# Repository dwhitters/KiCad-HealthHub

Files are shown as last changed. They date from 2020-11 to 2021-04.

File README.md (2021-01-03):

# KiCad-HealthHub
Schematic and PCB layout for the health hub.

## Overview
This PCB provides basic signal processing for an ECG input. The processed signal is then fed into a bluetooth module that can be used to provide data to a corresponding phone app, such as https://github.com/DaveAldon/Health-Hub-Mobile. Additional microcontroller pins are broken out to facilitate development of additional features.

## Images
Front

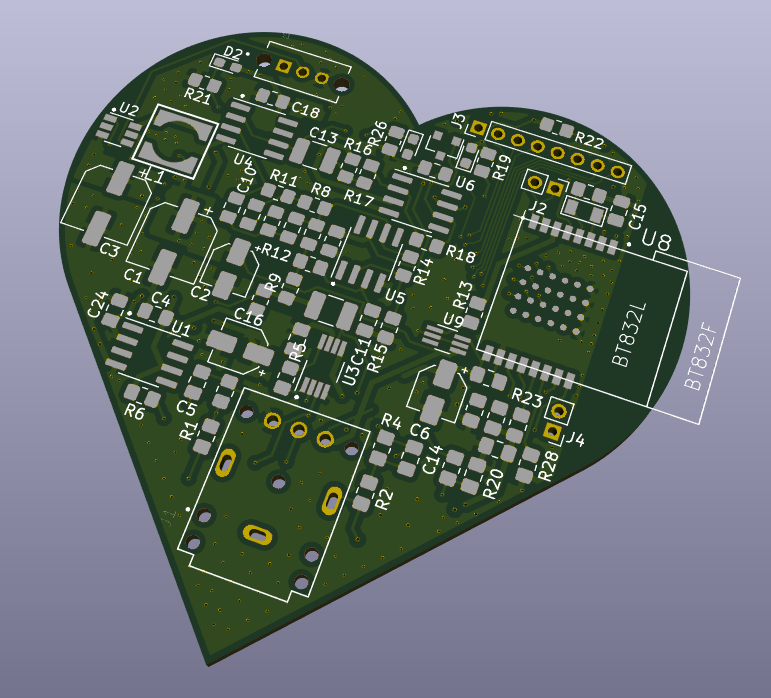
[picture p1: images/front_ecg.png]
Front


Back

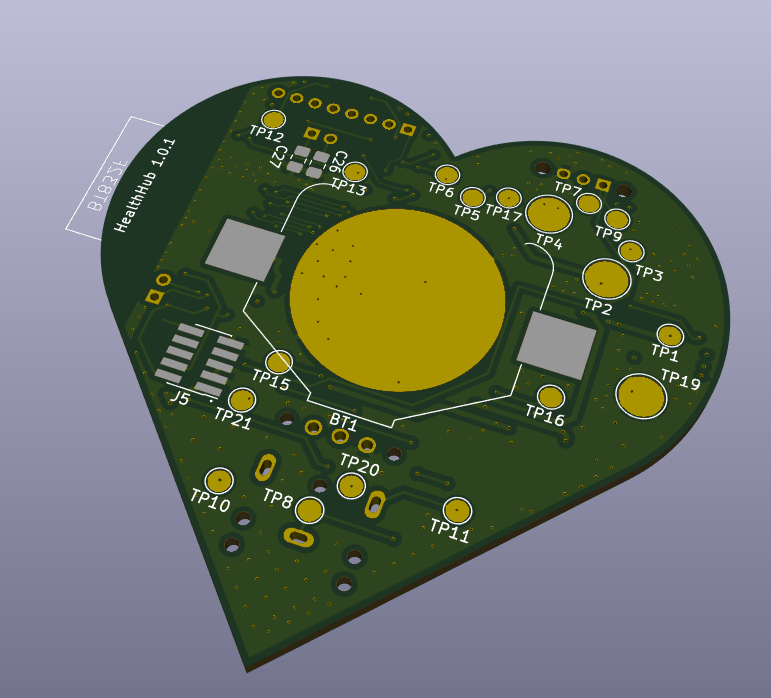
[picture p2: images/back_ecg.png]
Back


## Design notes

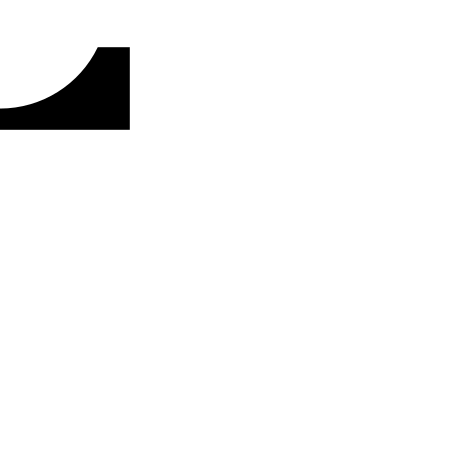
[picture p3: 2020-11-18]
Custom_Footprint/.svg2shenzhen-cache/images/F.SilkS_g23.png

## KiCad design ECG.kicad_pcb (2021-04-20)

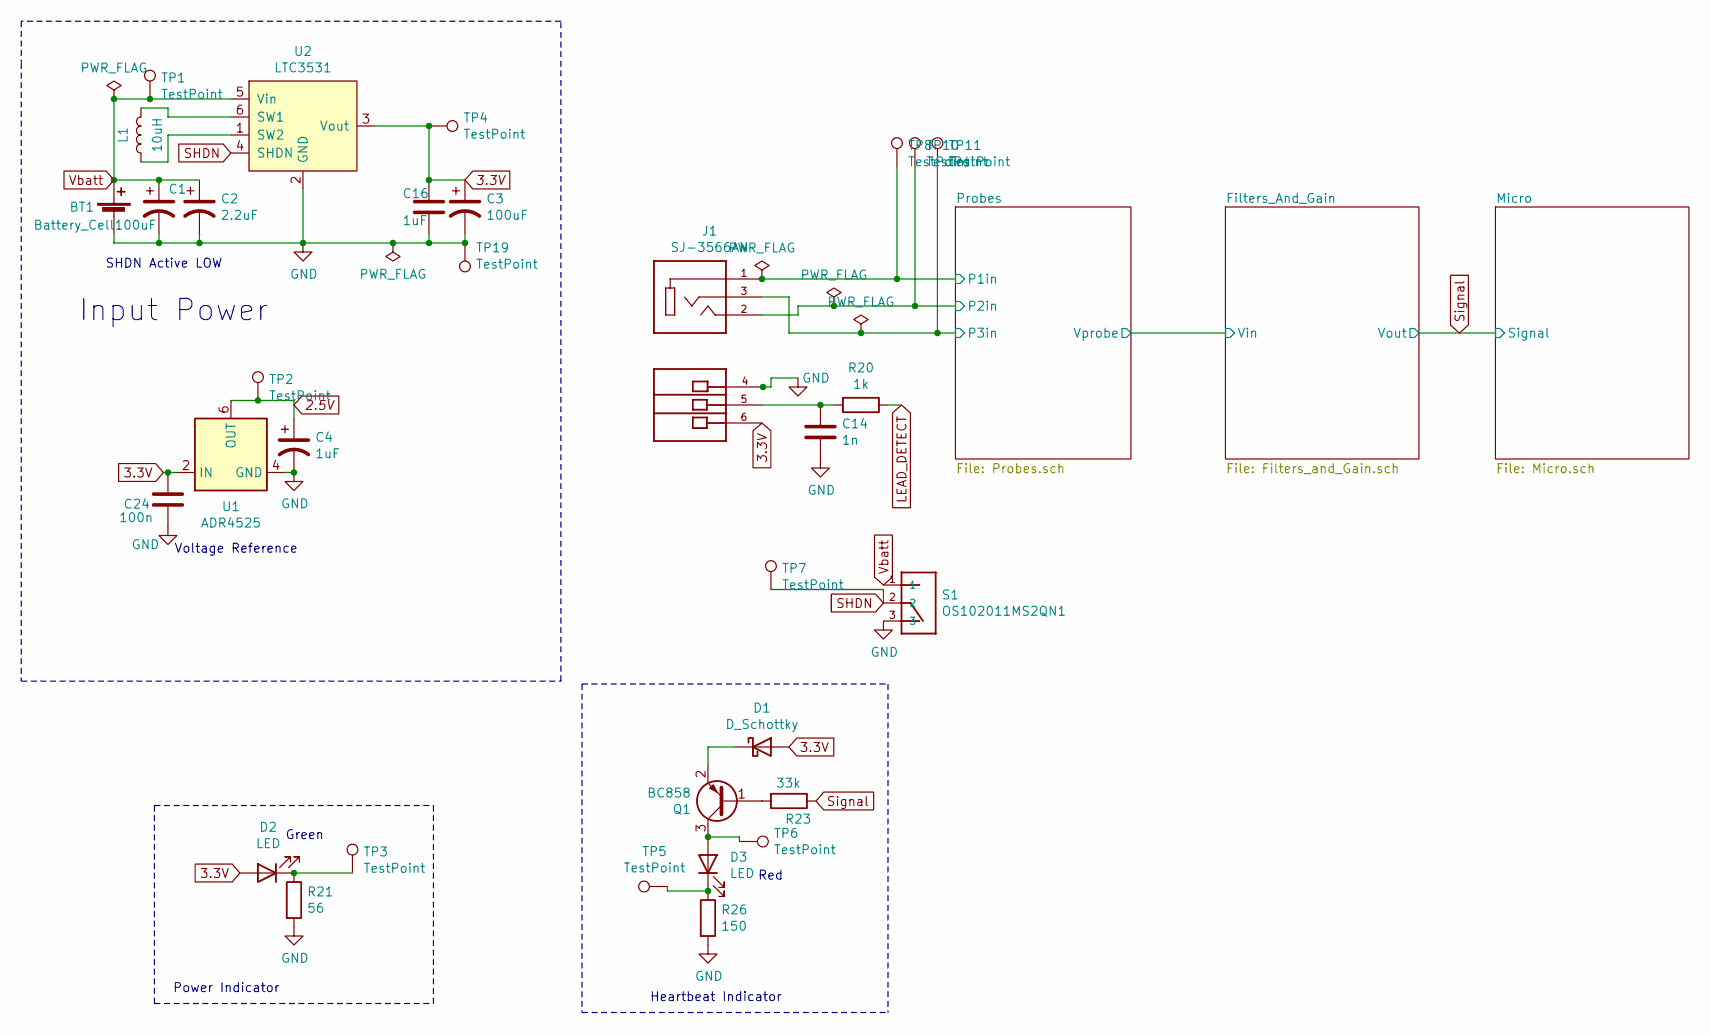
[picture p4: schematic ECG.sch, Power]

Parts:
BT1: Battery_Cell; BatteryHolder_Keystone_3008_1x2450
C1, C3: 100uF; CP_Elec_6.3x5.3
C2: 2.2uF; CP_Elec_4x5.7
C4: 1uF; C_0805_2012Metric_Pad1.18x1.45mm_HandSolder
C14: 1n; C_0805_2012Metric_Pad1.18x1.45mm_HandSolder
C16: 1uF; CP_Elec_4x5.3
C24: 100n; C_0805_2012Metric_Pad1.18x1.45mm_HandSolder
D1: D_Schottky; D_0603_1608Metric_Pad1.05x0.95mm_HandSolder
D2, D3: LED; D_0603_1608Metric_Pad1.05x0.95mm_HandSolder
J1: SJ-3566AN; CUI_SJ-3566AN
L1: 10uH; L_Sumida_CDRH5D28
Q1: BC858; SOT-23
R20: 1k; R_0805_2012Metric_Pad1.20x1.40mm_HandSolder
R21: 56; R_0805_2012Metric_Pad1.20x1.40mm_HandSolder
R23: 33k; R_0805_2012Metric_Pad1.20x1.40mm_HandSolder
R26: 150; R_0805_2012Metric_Pad1.20x1.40mm_HandSolder
S1: OS102011MS2QN1; SW_OS102011MS2QN1
TP1, TP3, TP5, TP6, TP7, TP8, TP10, TP11: TestPoint; TestPoint_Pad_D2.0mm
TP2, TP4, TP19: TestPoint; TestPoint_Pad_D4.0mm
U1: ADR4525; SOIC-8_3.9x4.9mm_P1.27mm
U2: LTC3531; TSOT-23-6

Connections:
2.5V: C4.1, TP2.1, U1.6 (OUT); also elsewhere on the board
3.3V: C3.1, C16.1, C24.1, D1.2 (A), D2.2 (A), J1.6, TP4.1, U1.2 (IN), U2.3 (Vout); also elsewhere on the board
/Probes/P1in: J1.1, TP8.1; also elsewhere on the board
/Probes/P2in: J1.2, TP10.1; also elsewhere on the board
/Probes/P3in: J1.3, TP11.1; also elsewhere on the board
GND: BT1.2 (-), C1.2, C2.2, C3.2, C4.2, C14.2, C16.2, C24.2, J1.4, R21.2, R26.2, S1.3, TP19.1, U1.4 (GND), U2.2 (GND); also elsewhere on the board
LEAD_DETECT: R20.1; also elsewhere on the board
unnamed: C14.1, J1.5, R20.2
unnamed: D1.1 (K), Q1.2 (E)
unnamed: D2.1 (K), R21.1, TP3.1
unnamed: D3.1 (K), R26.1, TP5.1
unnamed: D3.2 (A), Q1.3 (C), TP6.1
unnamed: L1.1, U2.1 (SW2)
unnamed: L1.2, U2.6 (SW1)
unnamed: Q1.1 (B), R23.2
SHDN: S1.2, TP7.1, U2.4 (SHDN); also elsewhere on the board
Signal: R23.1; also elsewhere on the board
Vbatt: BT1.1 (+), C1.1, C2.1, S1.1, TP1.1, U2.5 (Vin); also elsewhere on the board

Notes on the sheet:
Input Power
Voltage Reference
SHDN Active LOW
Power Indicator
Green
Red
Heartbeat Indicator

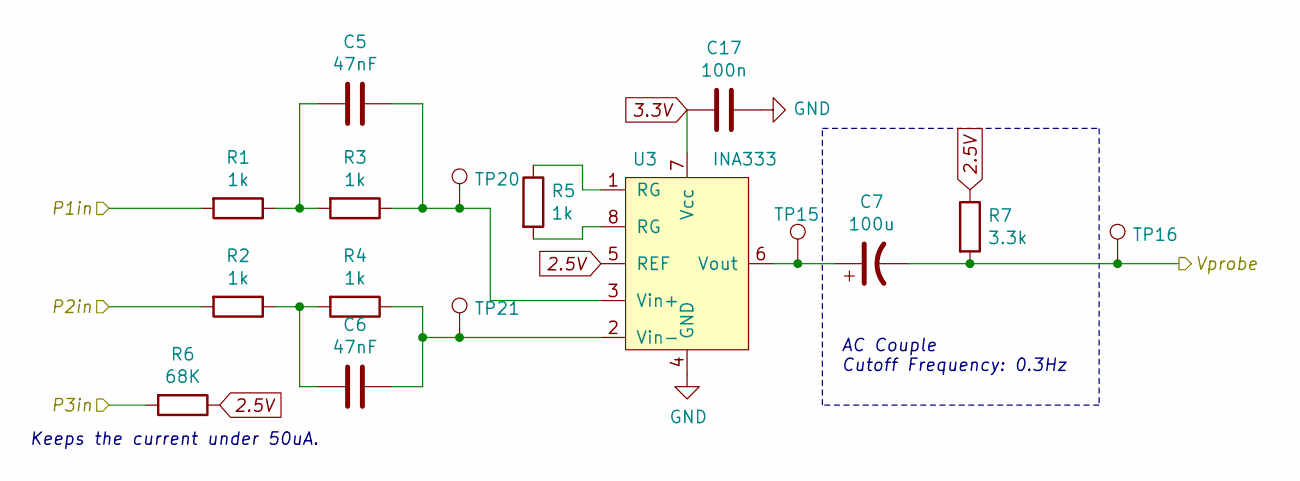
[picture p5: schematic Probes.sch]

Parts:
C5, C6: 47nF; C_0805_2012Metric_Pad1.18x1.45mm_HandSolder
C7: 100u; C_1210_3225Metric_Pad1.33x2.70mm_HandSolder
C17: 100n; C_0805_2012Metric_Pad1.18x1.45mm_HandSolder
R1, R2, R3, R4, R5: 1k; R_0805_2012Metric_Pad1.20x1.40mm_HandSolder
R6: 68K; R_0805_2012Metric_Pad1.20x1.40mm_HandSolder
R7: 3.3k; R_0805_2012Metric_Pad1.20x1.40mm_HandSolder
TP15, TP16, TP20, TP21: TestPoint; TestPoint_Pad_D2.0mm
U3: INA333; VSSOP-8_3.0x3.0mm_P0.65mm

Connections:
2.5V: R6.1, R7.1, U3.5 (REF); also elsewhere on the board
3.3V: C17.2, U3.7 (Vcc); also elsewhere on the board
/Filters_And_Gain/Vin: C7.2, R7.2, TP16.1; also elsewhere on the board
/Probes/P1in: R1.2; also elsewhere on the board
/Probes/P2in: R2.2; also elsewhere on the board
/Probes/P3in: R6.2; also elsewhere on the board
GND: C17.1, U3.4 (GND); also elsewhere on the board
unnamed: C5.1, R3.1, TP20.1, U3.3 (Vin+)
unnamed: C5.2, R1.1, R3.2
unnamed: C6.1, R4.1, TP21.1, U3.2 (Vin-)
unnamed: C6.2, R2.1, R4.2
unnamed: C7.1, TP15.1, U3.6 (Vout)
unnamed: R5.1, U3.1 (RG)
unnamed: R5.2, U3.8 (RG)

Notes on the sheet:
Keeps the current under 50uA.
AC Couple Cutoff Frequency: 0.3Hz

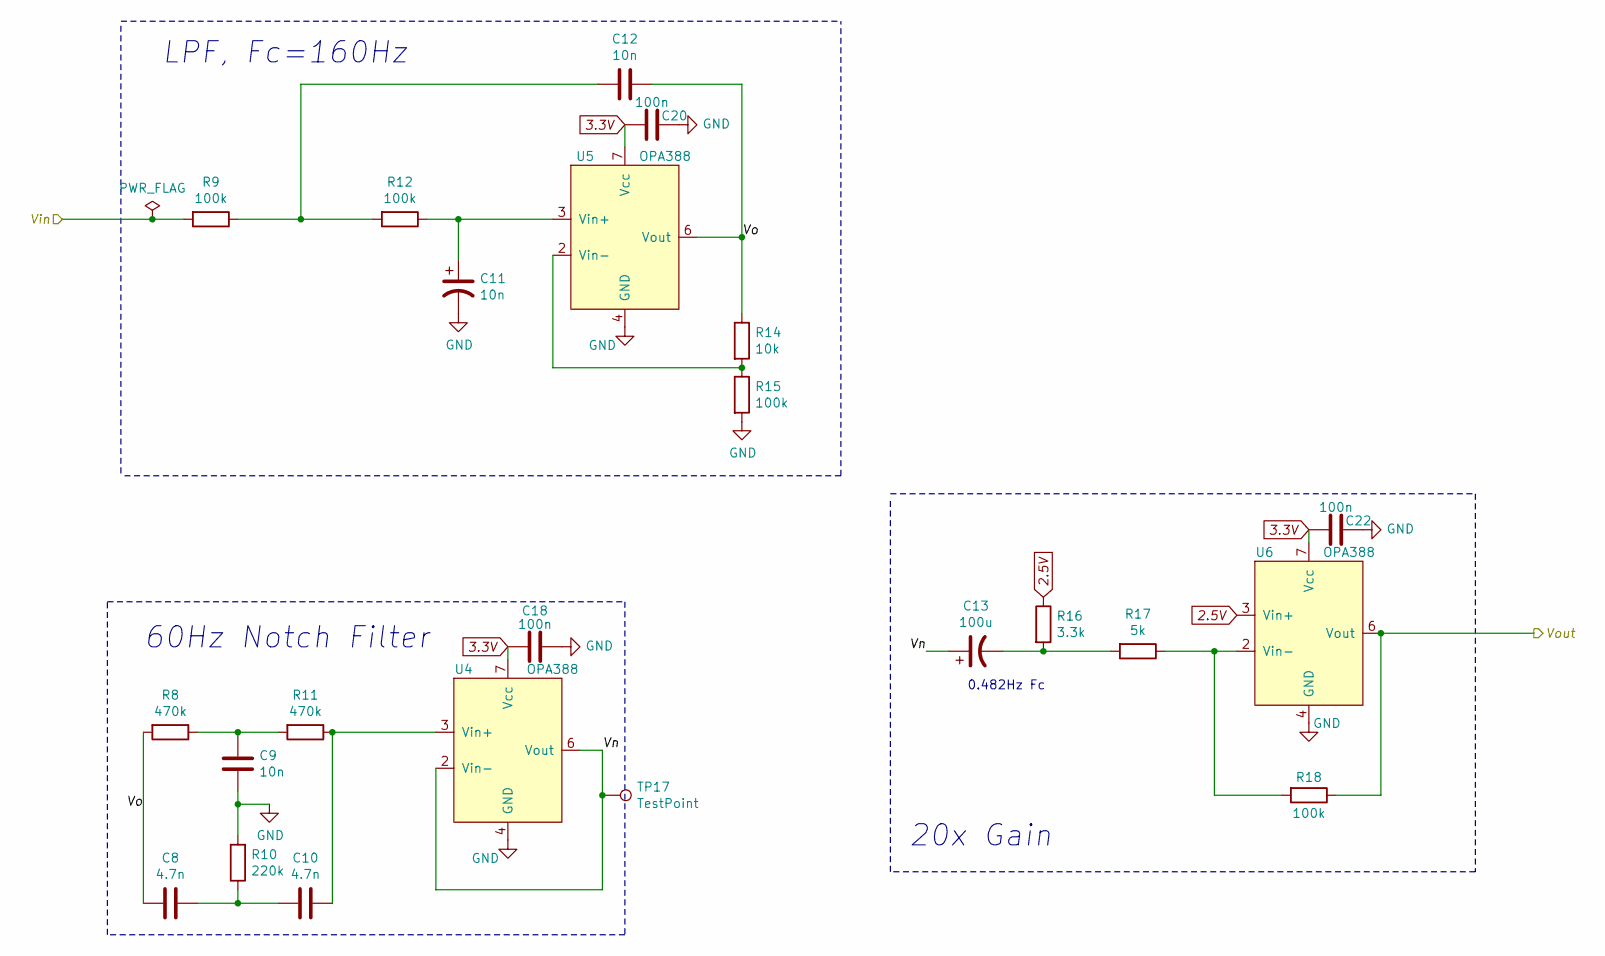
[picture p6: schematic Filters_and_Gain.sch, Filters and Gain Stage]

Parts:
C8, C10: 4.7n; C_0805_2012Metric_Pad1.18x1.45mm_HandSolder
C9, C11, C12: 10n; C_0805_2012Metric_Pad1.18x1.45mm_HandSolder
C13: 100u; C_1210_3225Metric_Pad1.33x2.70mm_HandSolder
C18, C20, C22: 100n; C_0805_2012Metric_Pad1.18x1.45mm_HandSolder
R8, R11: 470k; R_0805_2012Metric_Pad1.20x1.40mm_HandSolder
R9, R12, R15, R18: 100k; R_0805_2012Metric_Pad1.20x1.40mm_HandSolder
R10: 220k; R_0805_2012Metric_Pad1.20x1.40mm_HandSolder
R14: 10k; R_0805_2012Metric_Pad1.20x1.40mm_HandSolder
R16: 3.3k; R_0805_2012Metric_Pad1.20x1.40mm_HandSolder
R17: 5k; R_0805_2012Metric_Pad1.20x1.40mm_HandSolder
TP17: TestPoint; TestPoint_Pad_D2.0mm
U4, U5, U6: OPA388; SOIC-8_3.9x4.9mm_P1.27mm

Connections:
2.5V: R16.1, U6.3 (Vin+); also elsewhere on the board
3.3V: C18.1, C20.1, C22.1, U4.7 (Vcc), U5.7 (Vcc), U6.7 (Vcc); also elsewhere on the board
/Filters_And_Gain/Vin: R9.2; also elsewhere on the board
/Filters_And_Gain/Vn: C13.1, TP17.1, U4.2 (Vin-), U4.6 (Vout)
/Filters_And_Gain/Vo: C8.2, C12.2, R8.2, R14.1, U5.6 (Vout)
GND: C9.1, C11.2, C18.2, C20.2, C22.2, R10.2, R15.2, U4.4 (GND), U5.4 (GND), U6.4 (GND); also elsewhere on the board
unnamed: C9.2, R8.1, R11.2
unnamed: C10.1, R11.1, U4.3 (Vin+)
unnamed: C8.1, C10.2, R10.1
unnamed: C11.1, R12.1, U5.3 (Vin+)
unnamed: C12.1, R9.1, R12.2
unnamed: C13.2, R16.2, R17.2
unnamed: R14.2, R15.1, U5.2 (Vin-)
unnamed: R17.1, R18.2, U6.2 (Vin-)
Signal: R18.1, U6.6 (Vout); also elsewhere on the board

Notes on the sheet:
LPF, Fc=160Hz
20x Gain
0.482Hz Fc
60Hz Notch Filter

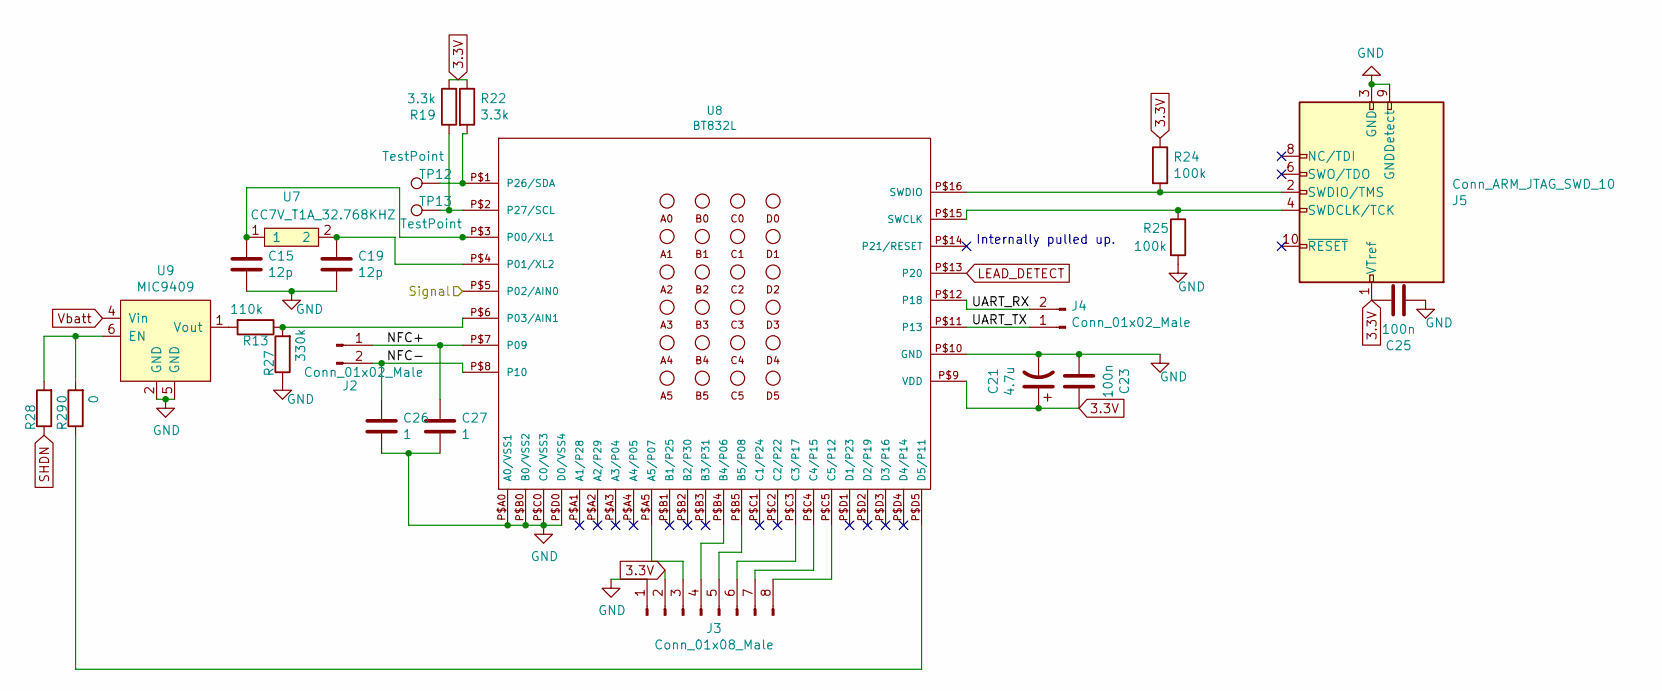
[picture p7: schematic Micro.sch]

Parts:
C15, C19: 12p; C_0805_2012Metric_Pad1.18x1.45mm_HandSolder
C21: 4.7u; CP_Elec_4x5.3
C23, C25: 100n; C_0805_2012Metric_Pad1.18x1.45mm_HandSolder
C26, C27: 1; C_0805_2012Metric_Pad1.18x1.45mm_HandSolder
J2, J4: Conn_01x02_Male; PinHeader_1x02_P2.00mm_Vertical
J3: Conn_01x08_Male; PinHeader_1x08_P2.00mm_Vertical
J5: Conn_ARM_JTAG_SWD_10; PinHeader_2x05_P1.27mm_Vertical_SMD
R13: 110k; R_0805_2012Metric_Pad1.20x1.40mm_HandSolder
R19, R22: 3.3k; R_0805_2012Metric_Pad1.20x1.40mm_HandSolder
R24, R25: 100k; R_0805_2012Metric_Pad1.20x1.40mm_HandSolder
R27: 330k; R_0805_2012Metric_Pad1.20x1.40mm_HandSolder
R28, R29: 0; R_0402_1005Metric_Pad0.72x0.64mm_HandSolder
TP12, TP13: TestPoint; TestPoint_Pad_D2.0mm
U7: CC7V_T1A_32.768KHZ; CC7V_T1A
U8: BT832L; BT832-BT832L
U9: MIC9409; SOT-363_SC-70-6_Handsoldering

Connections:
3.3V: C21.1, C23.1, C25.1, J3.2, J5.1 (VTref), R19.2, R22.1, R24.1, U8.P$9 (VDD); also elsewhere on the board
/Micro/NFC+: C27.1, J2.1, U8.P$7 (P09)
/Micro/NFC-: C26.1, J2.2, U8.P$8 (P10)
/Micro/UART_RX: J4.2, U8.P$12 (P18)
/Micro/UART_TX: J4.1, U8.P$11 (P13)
GND: C15.2, C19.2, C21.2, C23.2, C25.2, C26.2, C27.2, J3.1, J5.3 (GND), J5.5 (GND), J5.9 (GNDDetect), R25.2, R27.1, U8.P$10 (GND), U8.P$A0 (A0/VSS1), U8.P$B0 (B0/VSS2), U8.P$C0 (C0/VSS3), U8.P$D0 (D0/VSS4), U9.2 (GND), U9.5 (GND); also elsewhere on the board
LEAD_DETECT: U8.P$13 (P20); also elsewhere on the board
unnamed: C15.1, U7.1, U8.P$3 (P00/XL1)
unnamed: C19.1, U7.2, U8.P$4 (P01/XL2)
unnamed: J3.3, U8.P$A5 (A5/P07)
unnamed: J3.4, U8.P$B4 (B4/P06)
unnamed: J3.5, U8.P$B5 (B5/P08)
unnamed: J3.6, U8.P$C3 (C3/P17)
unnamed: J3.7, U8.P$C4 (C4/P15)
unnamed: J3.8, U8.P$C5 (C5/P12)
unnamed: J5.2 (SWDIO/TMS), R24.2, U8.P$16 (SWDIO)
unnamed: J5.4 (SWDCLK/TCK), R25.1, U8.P$15 (SWCLK)
unnamed: R13.1, R27.2, U8.P$6 (P03/AIN1)
unnamed: R13.2, U9.1 (Vout)
unnamed: R19.1, TP13.1, U8.P$2 (P27/SCL)
unnamed: R22.2, TP12.1, U8.P$1 (P26/SDA)
unnamed: R28.2, R29.2, U9.6 (EN)
unnamed: R29.1, U8.P$D5 (D5/P11)
SHDN: R28.1; also elsewhere on the board
Signal: U8.P$5 (P02/AIN0); also elsewhere on the board
Vbatt: U9.4 (Vin); also elsewhere on the board

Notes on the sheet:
Internally pulled up.

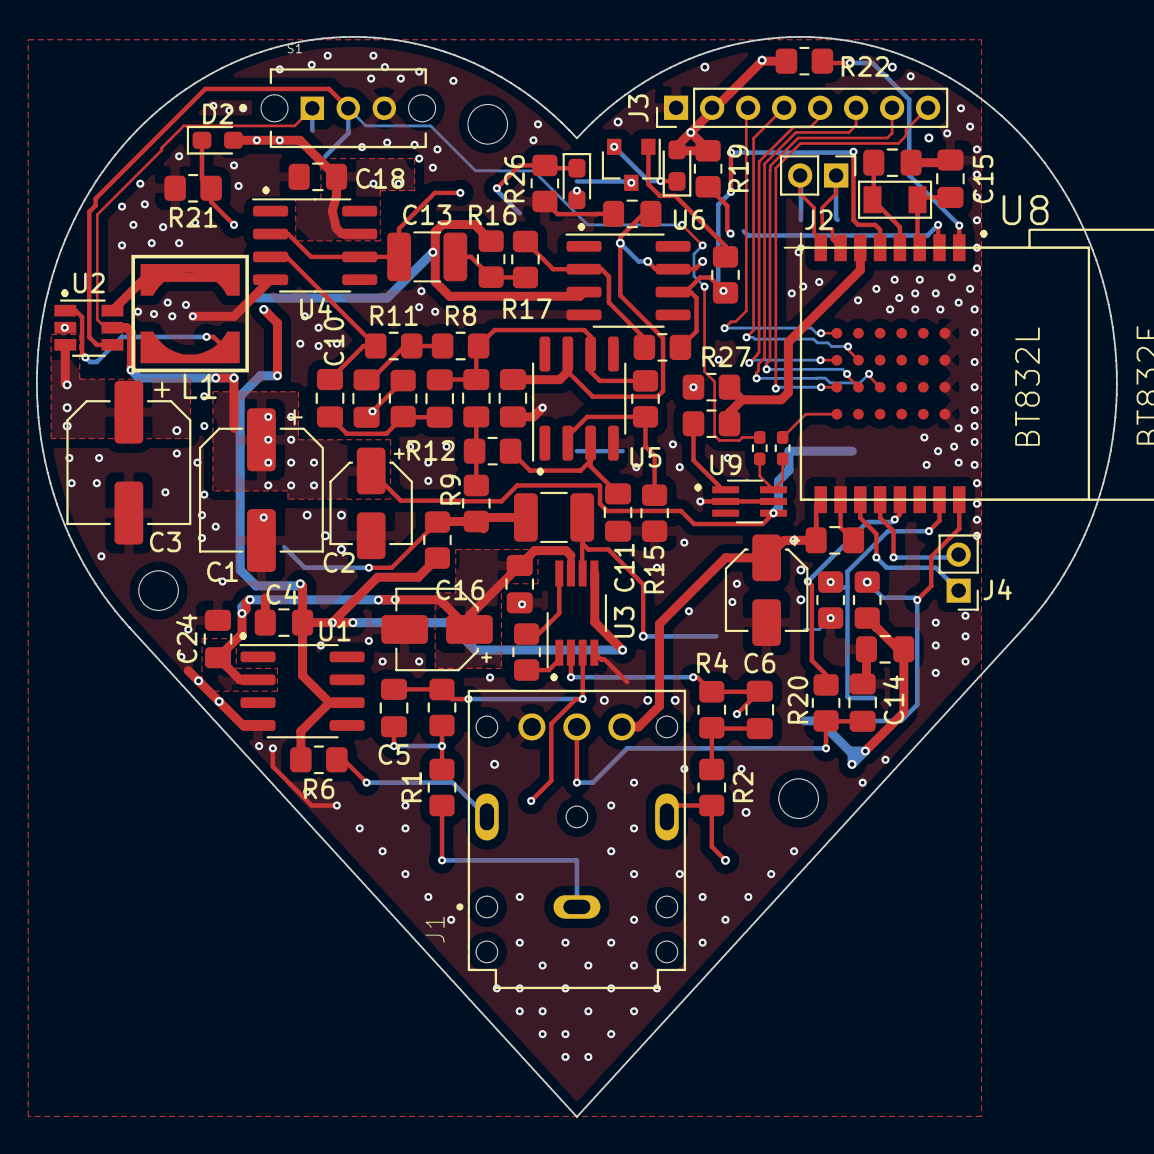
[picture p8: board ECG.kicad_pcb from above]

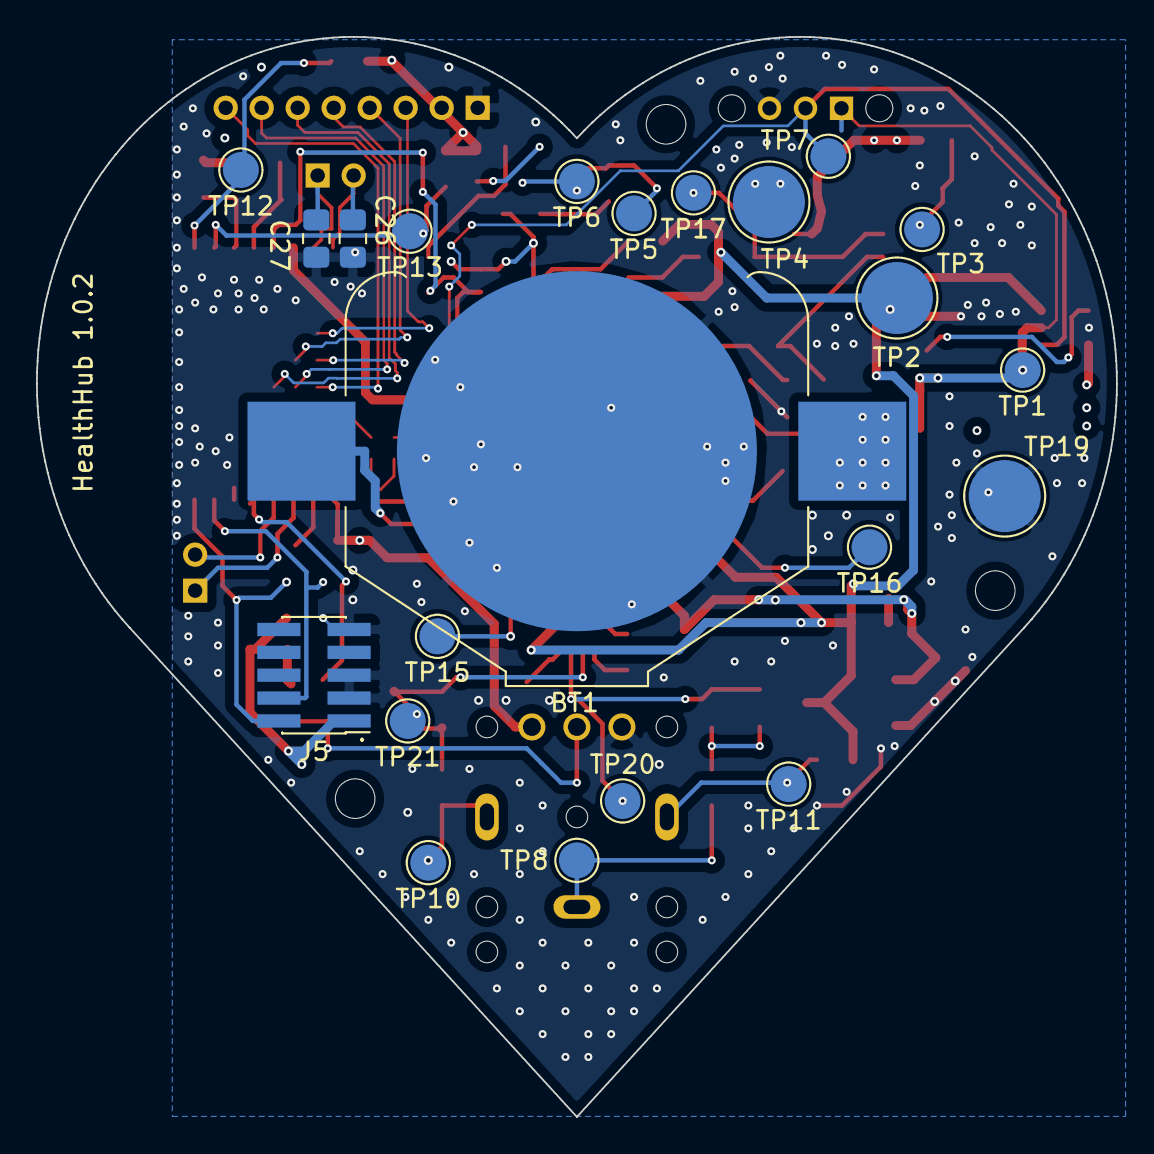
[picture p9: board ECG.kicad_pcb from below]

Board: 4 copper layers, 60.0 x 60.0 mm, 95 parts (22 on the bottom side), 56 nets.

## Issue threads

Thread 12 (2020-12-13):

Convert gain inverting circuit to non-inverting circuit

dwhitters, 2020-12-13:

dwhitters, 2020-12-16:
This is not required.

dwhitters, 2021-03-30:
Turns out this is required. The signal is getting clipped right now.

dwhitters, 2021-03-31:
The leads can be swapped on the wrists to invert the signal.

Closed 2021-03-31.

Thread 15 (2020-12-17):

Create NFC circuit

dwhitters, 2020-12-17:
Find an antenna and feed the signal to the NFC pins.

dwhitters, 2021-01-03:
Tuning capacitors were added to the NFC antenna traces.

Closed 2021-01-03.

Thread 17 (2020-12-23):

Reset not connected

xethm55, 2020-12-23:
Why is the reset line not connected?  Looks like there are two test points (one on arm connector and one on BT832).  Is the idea that if needed you could add the connection later?

dwhitters, 2020-12-26:
The reset line most likely will not need to be connected. I added pads just in case.

Closed 2020-12-26.

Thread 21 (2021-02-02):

Hook up switch to battery line

dwhitters, 2021-02-02:
The 3.3V was previously used; however, this doesn't turn on until the switch is turned on. And the switch doesn't turn anything on unless there's a 3.3V rail to draw from. Pull from the constant battery power source instead.

Closed 2021-02-04.

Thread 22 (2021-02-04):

Detach the battery ADC while the micro is not powered

dwhitters, 2021-02-04:
The battery power is backfed through the GPIO when the micro is not powered and the 3.3V rail is then "powered" at 1.4V.

Closed 2021-02-04.

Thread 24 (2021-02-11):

Test and Fix ECG Circuit

dwhitters, 2021-02-11:
AC couple needs a pull UP, not down from the INA333.

Closed 2021-03-01.

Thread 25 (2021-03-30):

Update active low pass filter

dwhitters, 2021-03-30:
It doesn't work as of now. It rails to the 3.3V rail.

Closed 2021-04-01.

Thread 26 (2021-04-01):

Investigate using voltage reference on the Nordic chip as a bias

dwhitters, 2021-04-01:
Lowering the input bias to the low pass filter will allow conversion to a second order Butterworth low pass filter. It's currently at 2.5V and the gain of a second order Butterworth LPF is 1.59 which pushes us over the 3.3V rail of the op amp.

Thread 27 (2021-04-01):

Fix gain stage clipping

dwhitters, 2021-04-01:
The 20x gain is being clipped and is distorting the signal.

dwhitters, 2021-04-08:
The clipping was due to the PNP base pulling the signal up to 3V - the PN junction voltage (~0.7V) whenever the signal dipped below it. A base resistor was added to limit the base current.

Closed 2021-04-08.

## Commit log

2020-10-27 Initial commit. Added voltage regulator and reference.
    [ECG.kicad_pcb, ECG.sch]
2020-10-28 Completed power circuits
    [ECG.sch]
2020-10-28 First pass at schematic complete
    [ECG.sch, Filters_and_Gain.sch, Probes.sch]
2020-11-12 Assigned footprints
    [ECG.sch, Filters_and_Gain.sch, Probes.sch]
2020-11-12 Added components to pcb
    [ECG.kicad_pcb]
2020-11-16 Added battery circuit
    [ECG.kicad_pcb, ECG.sch]
2020-11-18 #1 - Create PCB footprints
    [ECG.kicad_pcb, ECG.sch]
2020-11-23 #2 - Add ECG input via headphone jack
    [ECG.sch]
2020-11-24 #3 - Add power switch
    [ECG.kicad_pcb, ECG.sch]
2020-11-25 #7 - Add ADC
    [ECG.sch]
2020-12-02 #9 - Add heartbeat indicator
    [ECG.kicad_pcb, ECG.sch]
2020-12-02 #8 - Add test points. (Also updated filter circuit)
    [ECG.kicad_pcb, ECG.sch, Filters_and_Gain.sch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]
2020-12-03 #4 - Added the heart edge cut and updated the Kicad footprints that were removed
    [ECG.kicad_pcb, ECG.sch, Filters_and_Gain.sch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]
2020-12-04 Added bypass caps on ICs and fixed the SHDN input.
    [ECG.sch, Filters_and_Gain.sch, Probes.sch]
2020-12-04 Added bypass cap to Vref input
    [ECG.kicad_pcb, ECG.sch]
2020-12-05 Removed extra caps and removed the tantalum cap as it was too large
    [ECG.kicad_pcb, ECG.sch, Filters_and_Gain.sch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]
2020-12-05 Added battery voltage monitoring
    [ECG.kicad_pcb, ECG.sch]
2020-12-07 Added GND to I2C header and added ground and power planes.
    [ECG.kicad_pcb, ECG.sch]
2020-12-08 #4 - Initial component placement complete. Increased board size.
    [ECG.kicad_pcb, ECG.sch, Filters_and_Gain.sch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]
2020-12-08 #4 - Cleaned up ERC errors and updated the I2C pinout to increase board NET clearance
    [ECG.kicad_pcb, ECG.sch]
2020-12-10 #10 - Create BT symbol
    [ECG.kicad_pcb]
2020-12-12 #11 - Create BT Footprint
2020-12-13 #5 - Added 3.3V buck-boost regulator
    [ECG.sch, Filters_and_Gain.sch, Probes.sch]
2020-12-16 #13 and #5 - Updated circuits for 3.3V power rail
    [ECG.sch, Filters_and_Gain.sch]
2020-12-17 #6 - Add bluetooth module to board.
    [ECG.sch, Filters_and_Gain.sch, Micro.sch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]
2020-12-21 #6 #14 - Add bluetooth and flash header to board
    [ECG.kicad_pcb, ECG.sch, Micro.sch]
2020-12-21 #16 - Used Fanstel library
    [ECG.kicad_pcb, Micro.sch]
2020-12-26 #4 - Placed new components
    [ECG.kicad_pcb]
2020-12-29 Initial routing
    [ECG.kicad_pcb]
2020-12-30 #4 - Routed board
    [ECG.kicad_pcb, Filters_and_Gain.sch, Micro.sch]
2021-01-03 Added NFC tuning cap footprints, cleaned up silkscreen, and connected planes
    [ECG.kicad_pcb, Micro.sch]
2021-01-03 Added name and version to silkscreen
    [ECG.kicad_pcb]
2021-01-03 Added pin 1 designators
    [ECG.kicad_pcb]
2021-01-03 Fixed power and ground pours
    [ECG.kicad_pcb]
2021-01-04 Updated ground pour and fixed C23 silkscreen
    [ECG.kicad_pcb]
2021-02-04 #21 - Hook up switch to battery line
    [ECG.kicad_pcb, ECG.sch]
2021-02-04 #19 and #20 - Fix the micro debug and power connections
    [ECG.kicad_pcb, Micro.sch]
2021-02-04 #22 - Detach battery ADC while the micro is not powered
    [ECG.kicad_pcb, Micro.sch]
2021-02-04 Updated silk screen
    [ECG.kicad_pcb]
2021-02-11 #24 - Updated AC couple
    [ECG.kicad_pcb, Probes.sch]
2021-02-22 #23 - Add high side power switcher
    [ECG.kicad_pcb, Micro.sch]
2021-02-23 Removed test point tags
    [Probes.sch]
2021-03-01 #24 - Flip PNP and update low pass filter output resistors
    [ECG.sch, Filters_and_Gain.sch]
2021-03-01 #24 - Update layout with flipped PNP and update images
    [ECG.kicad_pcb]
2021-03-29 Added mounting holes, Added lead-detect to a micro GPIO, and removed requirement that the leads must be attached prior to turning on the device
    [ECG-B_Cu.gbr, ECG-B_Mask.gbr, ECG-B_SilkS.gbr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]
2021-03-29 Updated revision on PCB
    [ECG.kicad_pcb]
2021-03-29 Connected high side power switcher enable pin to SHDN net instead of 3.3V. Prevents feedback on the 3.3V net from registering as a logic high and keeping the power going through
    [ECG.kicad_pcb, Micro.sch]
2021-04-01 #25 - Updated low pass filter. Gain 2x -> 1x. Added ADC divider for battery to account for brand new batteries.
    [ECG.kicad_pcb, Filters_and_Gain.sch, Micro.sch]
2021-04-02 #28 - Remove pulldown from reset line on micro
    [ECG.kicad_pcb, Micro.sch]
2021-04-02 Updated debug header to include 3.3V and GND
    [ECG.kicad_pcb, Micro.sch]
2021-04-08 #27 - Fix gain stage clipping
    [ECG.kicad_pcb, ECG.sch]
2021-04-08 Prettified the board and removed old gerbers
    [ECG-B_Cu.gbr, ECG-B_Mask.gbr, ECG-B_SilkS.gbr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]
2021-04-20 Moved silkscreen references on PCB
    [ECG.kicad_pcb]
